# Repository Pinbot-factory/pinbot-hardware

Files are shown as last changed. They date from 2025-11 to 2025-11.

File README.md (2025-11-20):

**Pinbot** is an open-source platform for quickly building test jigs for electronics QA. The platform is made up of mechanical fixtures, control electronics, jig-level software and backend to store all test results.

**This repo is in active development. New HW will be released soon.**

## Pinbot Hardware
This repo is dedicated for electronics of a typical Pinbot jig. Now it is a compact carrier board for Raspberry Pi 0.

**It features:**
- 8 channels ADC 0-24V
- 8 channels GPIO 0-24V
- 4 signal relays
- USB hub (4x, with power control)
- Qwiic connector for I2C
- USB-C for power supply

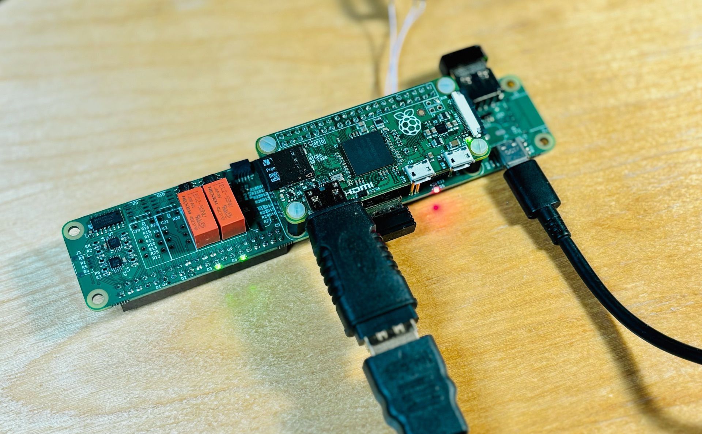
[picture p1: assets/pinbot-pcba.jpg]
Pinbot PCBA


Carrier board is 150x30mm. Repo includes KiCAD source files, generated gerbers, BOM, and everything to produce it on your own.

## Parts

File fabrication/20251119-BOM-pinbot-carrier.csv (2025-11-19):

Reference | Value | Footprint | Qty | DNP | LCSC Part # | Mouser Part #
A1 | Raspberry Pi Zero v1.3 | Raspberry_Pi_Zero_v.1.3_Hat:RASPI_ZERO_FULL | 1
C1,C4,C5,C6,C7,C9,C10,C17,C18,C19,C20,C21,C22,C23 | 0.1uFx50V | Capacitor_SMD:C_0603_1608Metric | 14 |  | C282519 | CGA3E2X7R1H104M080AA
C2 | 0.01uFx50V | Capacitor_SMD:C_0603_1608Metric | 1 |  | C100042 | 06031C103K4T4A
C3,C8,C12,C13,C14 | 100uFx16V | Capacitor_SMD:CP_Elec_6.3x5.4 | 5 |  | C129250 | UWT1C101MCL1GB
C11,C15,C16 | 10uFx10V | Capacitor_SMD:C_0603_1608Metric | 3 |  | C2959727 | GRM188Z71A106MA73J
D1,D2,D3,D4,D6,D7,D8,D9 | LTST-S270KGKT | LED_0603_1608Metric_side:LED_0603_1608Metric_side | 8 |  | C125113 | LTST-S270KGKT
D5 | LTST-S270KRKT | LED_0603_1608Metric_side:LED_0603_1608Metric_side | 1 |  | C125114 | LTST-S270KRKT
D10,D11,D12,D13,D14,D15,D16,D17 | ESD5Z3.3T5G | Diode_SMD:D_SOD-523 | 8 |  | C22440077 | ESD5Z3.3T5G
F1 | MF-NSMF200-2 | Fuse:Fuse_1206_3216Metric | 1 |  | C89656 | MF-NSMF200-2
H1,H2,H3,H4 | MountingHole | MountingHoles:MountingHole_3.2mm_M3_keepouts | 4 | DNP
J1 | USB4105-GF-A-120 | Connector_USB:USB_C_Receptacle_GCT_USB4105-xx-A_16P_TopMnt_Horizontal | 1 |  | C709358 | USB4105-GF-A-120
J2 | Conn_02x20_Odd_Even | Connector_PinSocket_2.54mm:PinSocket_2x20_P2.54mm_Vertical | 1 |  | C2977589
J3 | HC-1.0-4PWT | Connector_JST:JST_SH_SM04B-SRSS-TB_1x04-1MP_P1.00mm_Horizontal | 1 |  | C2845363 | 10147606-00004LF
J4 | SM06B-SRSS-TB | SM06B-SRSS-TB:JST_SM06B-SRSS-TB | 1 |  | C160405 | 10147606-00006LF
J5,J6,J7 | USB_A | USB1125-GF-B:GCT_USB1125-GF-B_REVA | 3 |  | C5984324 | USB1125-GF-B
JP1,JP2 | SolderJumper_2_Open | Jumper:SolderJumper-2_P1.3mm_Open_RoundedPad1.0x1.5mm | 2 | DNP
K1,K2,K3,K4 | EC2-5SNU | Relay_THT:Relay_DPDT_Kemet_EC2 | 4 |  | C2153173 | EC2-5SNU
R1,R2,R3,R4,R12,R13,R14,R15 | 820k | Resistor_SMD:R_0603_1608Metric | 8 |  | C2907070 | ERJ-3EKF8203V
R5,R6,R8,R9,R16,R17,R20,R25 | 120k | Resistor_SMD:R_0603_1608Metric | 8 |  | C2930027 | CRGCQ0603F120K
R7 | 1M | Resistor_SMD:R_0603_1608Metric | 1 |  | C107698 | ASC0603-1M0FT5
R10,R11 | 5.1k | Resistor_SMD:R_0603_1608Metric | 2 |  | C2907114 | ERJ-3EKF5101V
R18,R19,R21,R22,R23,R24,R26,R27,R35,R36,R37,R42,R43 | 10k | Resistor_SMD:R_0603_1608Metric | 13 |  | C2907113 | RMC1/16K1002DTP
R28 | 100R | Resistor_SMD:R_0603_1608Metric | 1 |  | C2907089 | CRT0603-DY-1000ELF
R29,R30,R31,R32,R33,R34,R39,R40,R41 | 330R | Resistor_SMD:R_0603_1608Metric | 9 |  | C23138 | RMCF0603FT330R
R38 | 2.7k | Resistor_SMD:R_0603_1608Metric | 1 |  | C13167 | AC0603FR-102K7L
U1 | TCA9535PWR | Package_SO:TSSOP-24_4.4x7.8mm_P0.65mm | 1 |  | C22396388 | TCA9535PWR
U2,U7 | ADS1015IDGS | Package_SO:TSSOP-10_3x3mm_P0.5mm | 2 |  | C193969 | ADS1015IDGS
U8 | 74HC04 | Package_SO:SOIC-14_3.9x8.7mm_P1.27mm | 1 |  | C5590 | 74HC04D,653
U9,U10,U11,U12 | ZXBM5210-S | Package_SO:SOIC-8_3.9x4.9mm_P1.27mm | 4 |  | C20627211 | ZXBM5210-S
U13,U19 | MIC2026-2xM | Package_SO:SOIC-8_3.9x4.9mm_P1.27mm | 2 |  | C148072 | MIC2026-2YM
U14,U15,U16,U17 | USBLC6-2SC6 | Package_TO_SOT_SMD:SOT-23-6 | 4 |  | C5180249 | USBLC6-2SC6
U18 | FE1.1s | Package_SO:SSOP-28_3.9x9.9mm_P0.635mm | 1 |  | C9359
Y1 | 12MHz | Crystal:Crystal_SMD_3225-4Pin_3.2x2.5mm | 1 |  | C70565 | ECS-120-12-33-AEN-TR

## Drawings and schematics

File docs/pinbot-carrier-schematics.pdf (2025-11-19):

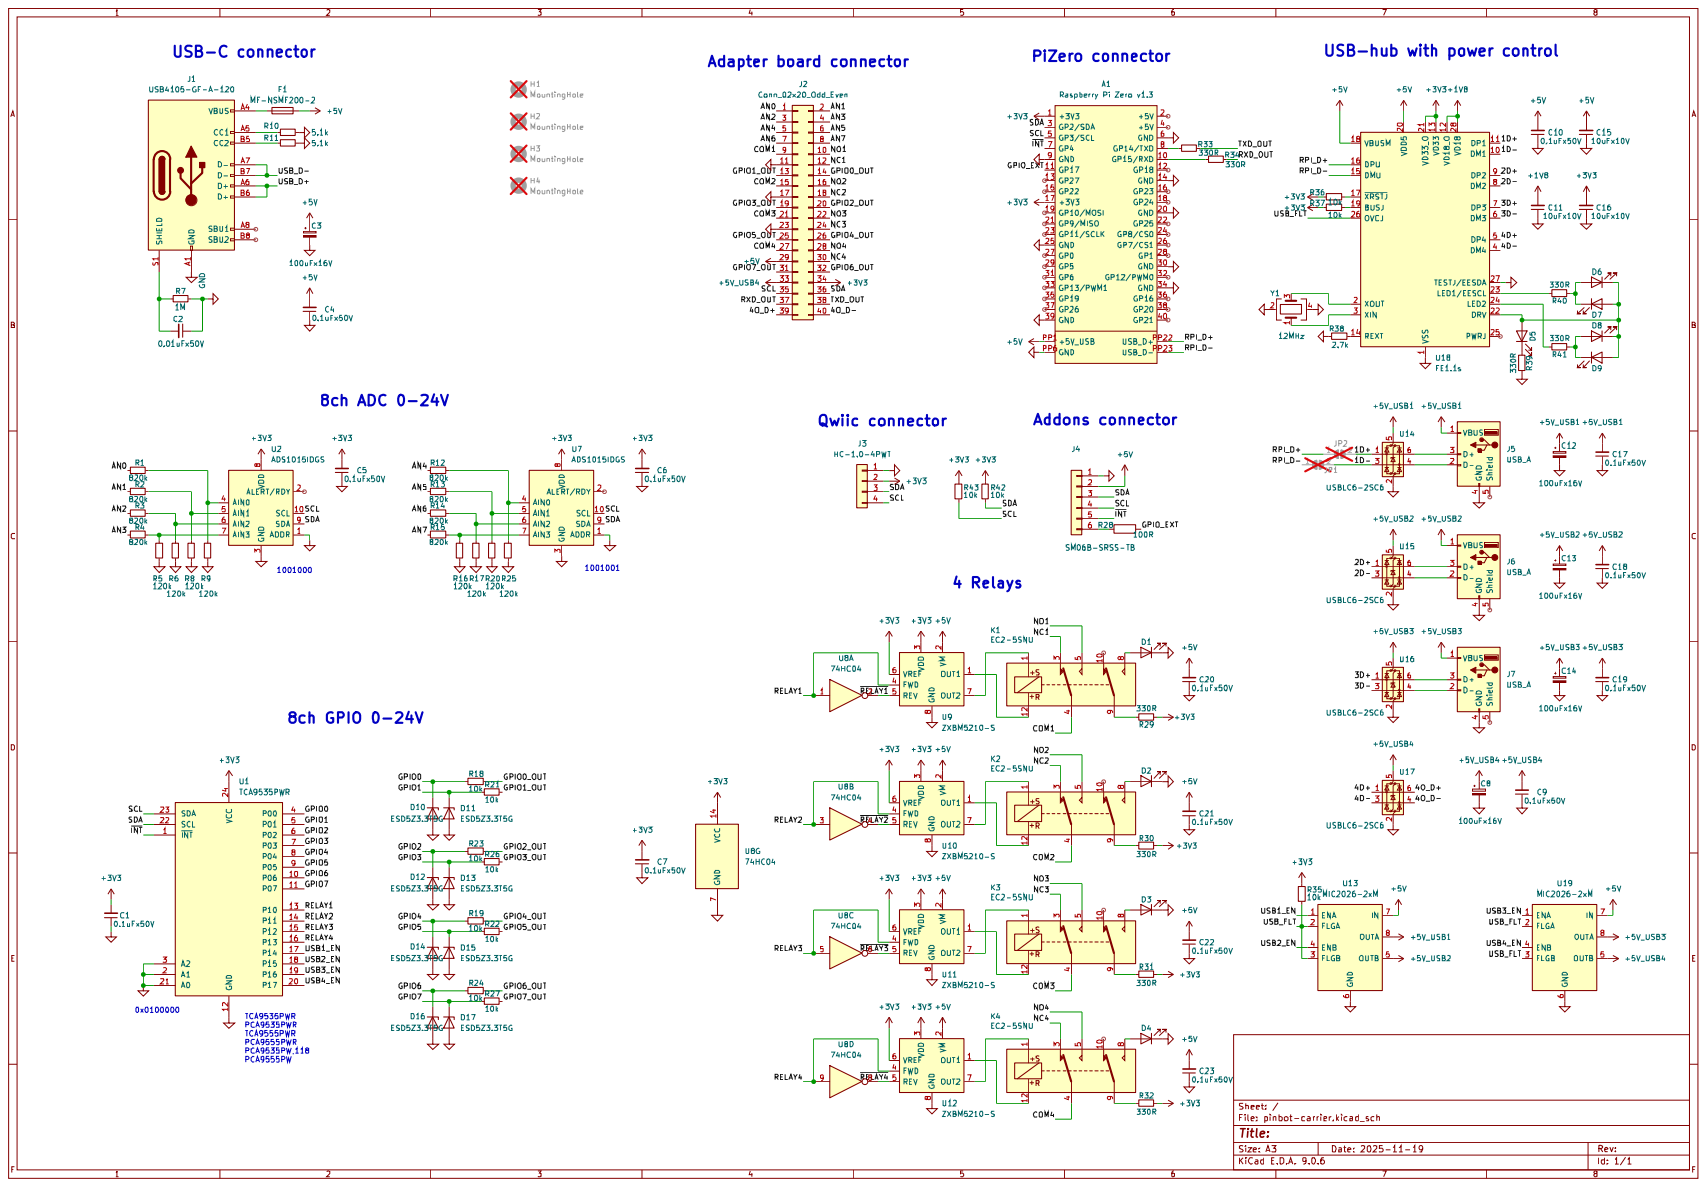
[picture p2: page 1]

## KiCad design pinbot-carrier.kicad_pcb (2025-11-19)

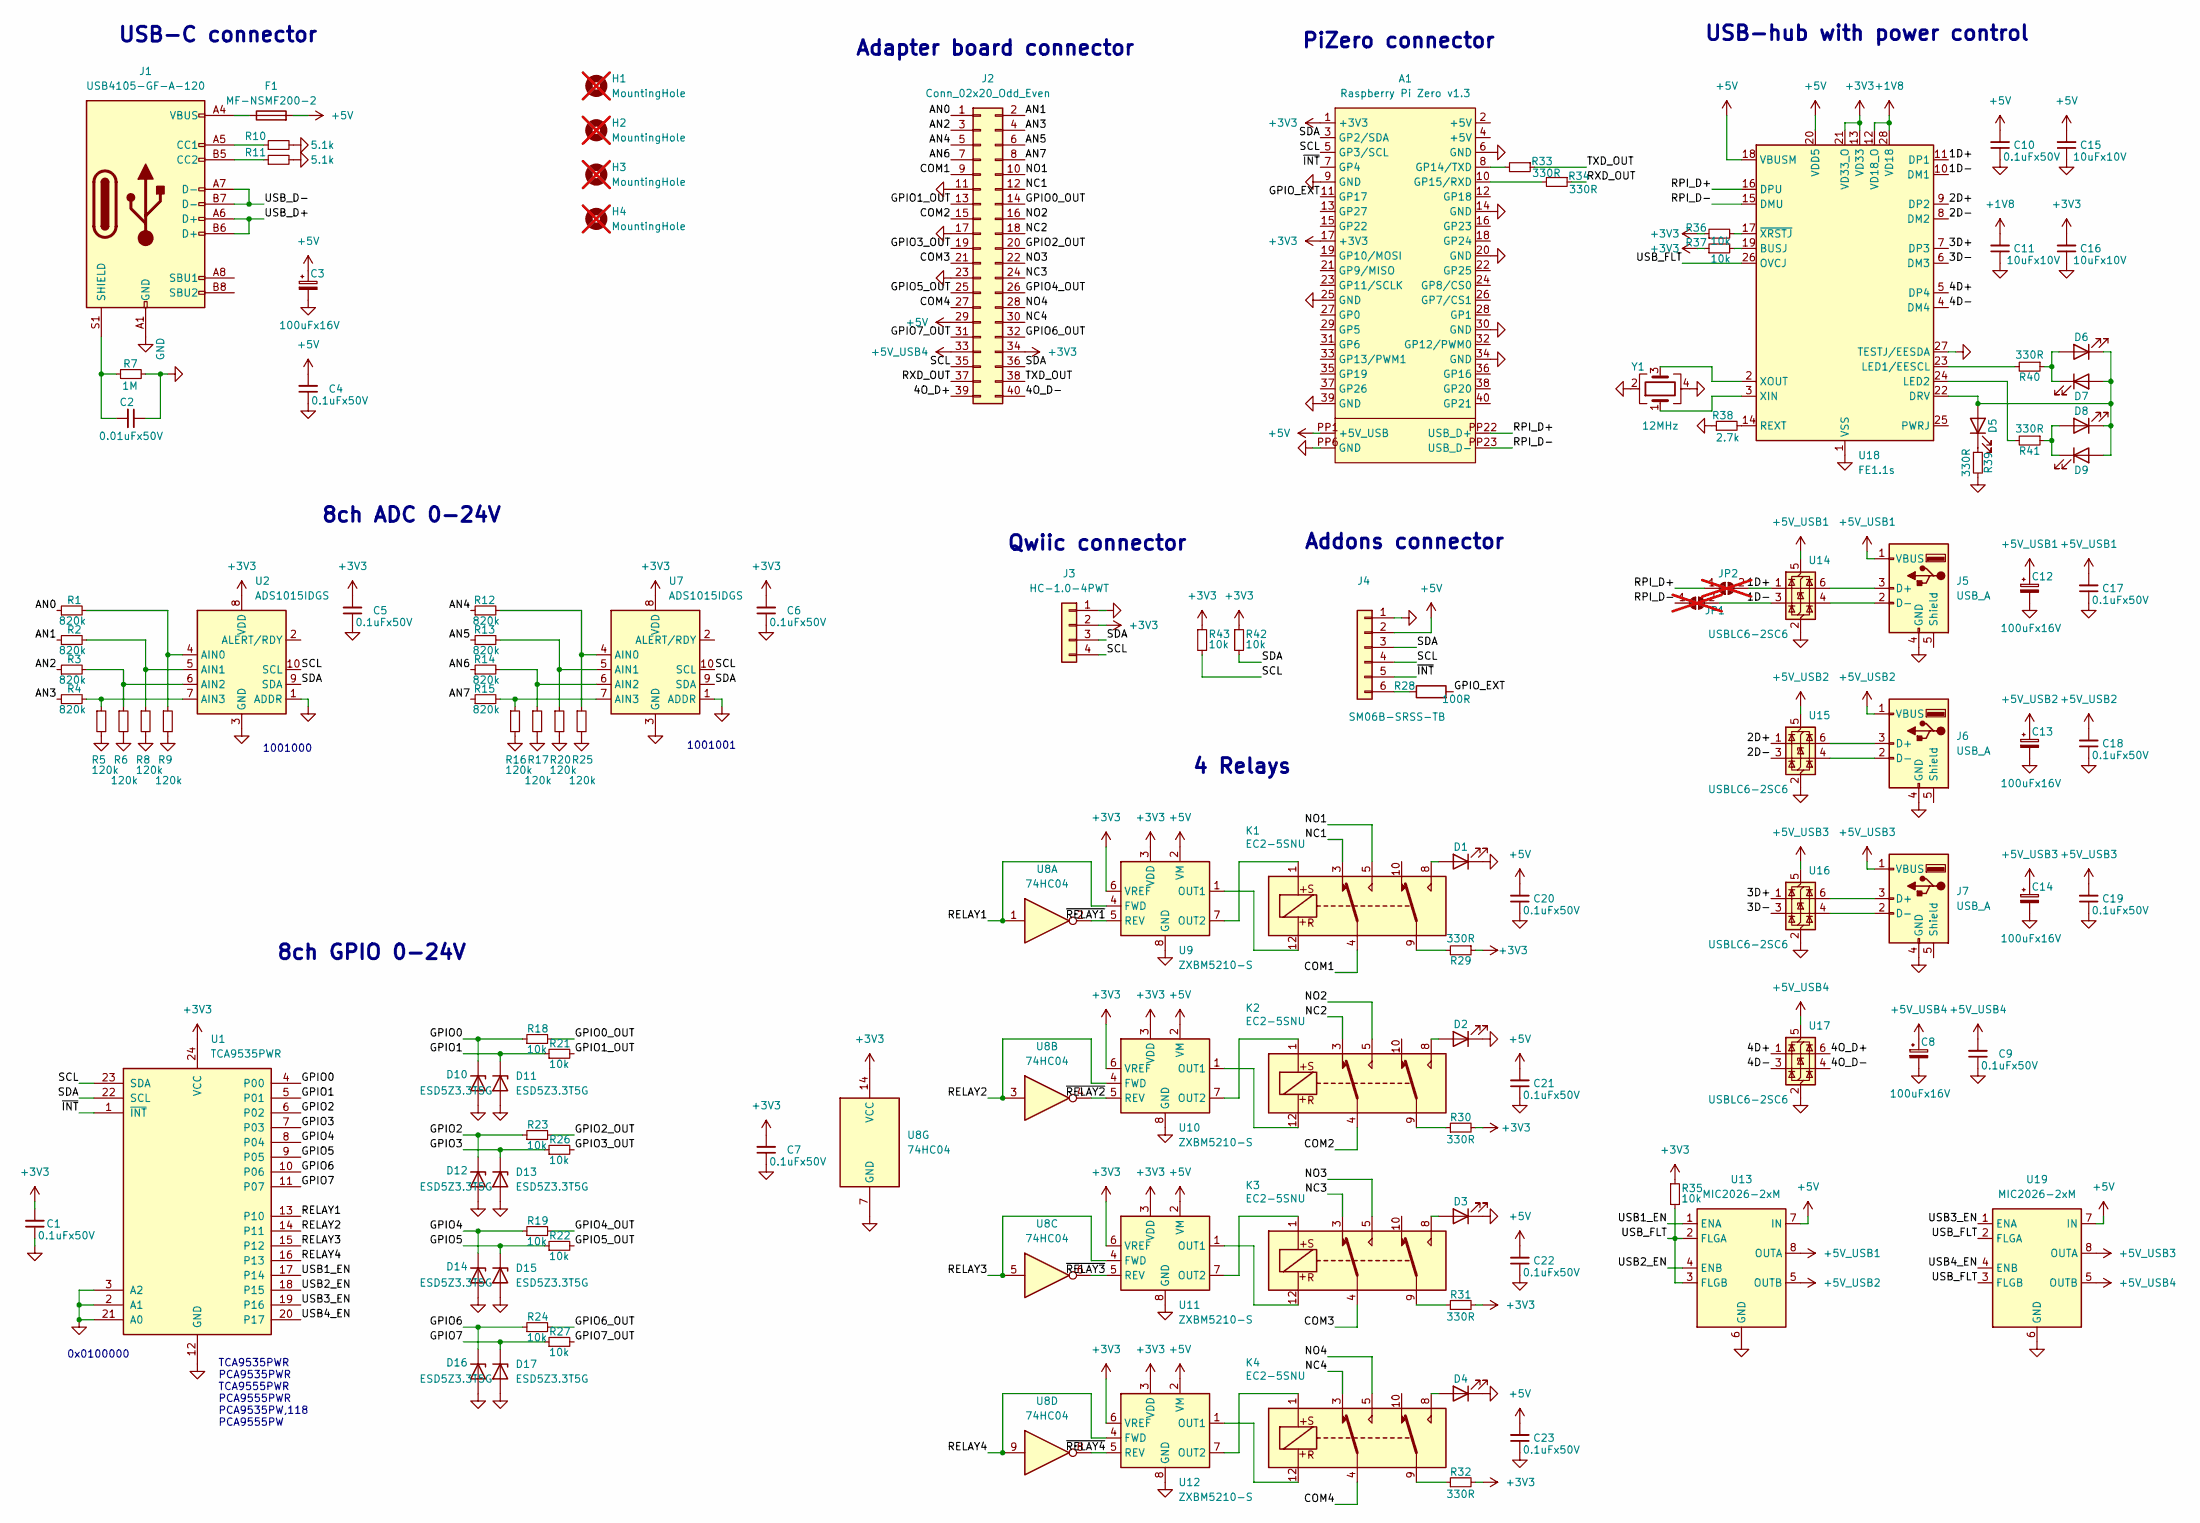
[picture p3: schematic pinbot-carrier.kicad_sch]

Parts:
A1: Raspberry Pi Zero v1.3; RASPI_ZERO_FULL
C1: 0.1uFx50V; C_0603_1608Metric; Mouser Part # CGA3E2X7R1H104M080AA
C2: 0.01uFx50V; C_0603_1608Metric; Mouser Part # 06031C103K4T4A; LCSC Part # C100042
C3, C8, C12, C13, C14: 100uFx16V; CP_Elec_6.3x5.4; Mouser Part # UWT1C101MCL1GB; LCSC Part # C129250
C4, C5, C6, C7, C9, C10, C17, C18, C19, C20, C21, C22, C23: 0.1uFx50V; C_0603_1608Metric; Mouser Part # CGA3E2X7R1H104M080AA; LCSC Part # C282519
C11, C15, C16: 10uFx10V; C_0603_1608Metric; Mouser Part # GRM188Z71A106MA73J; LCSC Part # C2959727
D1, D2, D3, D4, D6, D7, D8, D9: LTST-S270KGKT; LED_0603_1608Metric_side; Mouser Part # LTST-S270KGKT; LCSC Part # C125113
D5: LTST-S270KRKT; LED_0603_1608Metric_side; Mouser Part # LTST-S270KRKT; LCSC Part # C125114
D10, D11, D12, D13, D14, D15, D16, D17: ESD5Z3.3T5G; D_SOD-523; Mouser Part # ESD5Z3.3T5G
F1: MF-NSMF200-2; Fuse_1206_3216Metric; Mouser Part # MF-NSMF200-2; LCSC Part # C89656
H1, H2, H3, H4: MountingHole; MountingHole_3.2mm_M3_keepouts; not fitted
J1: USB4105-GF-A-120; USB_C_Receptacle_GCT_USB4105-xx-A_16P_TopMnt_Horizontal; Mouser Part # USB4105-GF-A-120
J2: Conn_02x20_Odd_Even; PinSocket_2x20_P2.54mm_Vertical; LCSC Part # C2977589
J3: HC-1.0-4PWT; JST_SH_SM04B-SRSS-TB_1x04-1MP_P1.00mm_Horizontal; Mouser Part # 10147606-00004LF; LCSC Part # C2845363
J4: SM06B-SRSS-TB; JST_SM06B-SRSS-TB; Mouser Part # 10147606-00006LF; LCSC Part # C160405
J5, J6, J7: USB_A; GCT_USB1125-GF-B_REVA; Mouser Part # USB1125-GF-B
JP1, JP2: SolderJumper_2_Open; SolderJumper-2_P1.3mm_Open_RoundedPad1.0x1.5mm; not fitted
K1, K2, K3, K4: EC2-5SNU; Relay_DPDT_Kemet_EC2; Mouser Part # EC2-5SNU
R1, R2, R3, R4, R12, R13, R14, R15: 820k; R_0603_1608Metric; Mouser Part # ERJ-3EKF8203V; LCSC Part # C2907070
R5, R6, R8, R9, R16, R17, R20, R25: 120k; R_0603_1608Metric; Mouser Part # CRGCQ0603F120K; LCSC Part # C2930027
R7: 1M; R_0603_1608Metric; Mouser Part # ASC0603-1M0FT5; LCSC Part # C107698
R10, R11: 5.1k; R_0603_1608Metric; Mouser Part # ERJ-3EKF5101V; LCSC Part # C2907114
R18, R19, R21, R22, R23, R24, R26, R27, R35, R36, R37, R42, R43: 10k; R_0603_1608Metric; Mouser Part # RMC1/16K1002DTP; LCSC Part # C2907113
R28: 100R; R_0603_1608Metric; Mouser Part # CRT0603-DY-1000ELF; LCSC Part # C2907089
R29, R30, R31, R32, R33, R34, R39, R40, R41: 330R; R_0603_1608Metric; Mouser Part # RMCF0603FT330R; LCSC Part # C23138
R38: 2.7k; R_0603_1608Metric; Mouser Part # AC0603FR-102K7L; LCSC Part # C13167
U1: TCA9535PWR; TSSOP-24_4.4x7.8mm_P0.65mm; Mouser Part # TCA9535PWR
U2, U7: ADS1015IDGS; TSSOP-10_3x3mm_P0.5mm; Mouser Part # ADS1015IDGS
U8: 74HC04; SOIC-14_3.9x8.7mm_P1.27mm; Mouser Part # 74HC04D,653
U9, U10, U11, U12: ZXBM5210-S; SOIC-8_3.9x4.9mm_P1.27mm; Mouser Part # ZXBM5210-S
U13, U19: MIC2026-2xM; SOIC-8_3.9x4.9mm_P1.27mm; Mouser Part # MIC2026-2YM
U14, U15, U16, U17: USBLC6-2SC6; SOT-23-6; Mouser Part # USBLC6-2SC6
U18: FE1.1s; SSOP-28_3.9x9.9mm_P0.635mm; LCSC Part # C9359
Y1: 12MHz; Crystal_SMD_3225-4Pin_3.2x2.5mm; PartNumber X322512MOB4SI; LCSC Part # C70565

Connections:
+1V8: C11.2, U18.12 (VD18_O), U18.28 (VD18)
+3V3: A1.1 (+3V3), A1.17 (+3V3), C1.2, C5.2, C6.2, C7.2, C16.2, J2.34, J3.2, R29.1, R30.2, R31.2, R32.2, R35.1, R36.1, R37.1, R42.1, R43.1, U1.24 (VCC), U2.8 (VDD), U7.8 (VDD), U8.14 (VCC), U9.3 (VDD), U9.6 (VREF), U10.3 (VDD), U10.6 (VREF), U11.3 (VDD), U11.6 (VREF), U12.3 (VDD), U12.6 (VREF), U18.13 (VD33), U18.21 (VD33_O)
+5V: A1.PP1 (+5V_USB), C3.1, C4.2, C10.2, C15.2, C20.2, C21.2, C22.2, C23.2, F1.2, J2.29, J4.2, U9.2 (VM), U10.2 (VM), U11.2 (VM), U12.2 (VM), U13.7 (IN), U18.18 (VBUSM), U18.20 (VDD5), U19.7 (IN)
+5V_USB1: C12.1, C17.2, J5.1 (VBUS), U13.8 (OUTA), U14.5 (VBUS)
+5V_USB2: C13.1, C18.2, J6.1 (VBUS), U13.5 (OUTB), U15.5 (VBUS)
+5V_USB3: C14.1, C19.2, J7.1 (VBUS), U16.5 (VBUS), U19.8 (OUTA)
+5V_USB4: C8.1, C9.2, J2.33, U17.5 (VBUS), U19.5 (OUTB)
/1D+: JP2.2 (B), U14.1 (I/O1), U18.11 (DP1)
/1D-: JP1.2 (B), U14.3 (I/O2), U18.10 (DM1)
/2D+: U15.1 (I/O1), U18.9 (DP2)
/2D-: U15.3 (I/O2), U18.8 (DM2)
/3D+: U16.1 (I/O1), U18.7 (DP3)
/3D-: U16.3 (I/O2), U18.6 (DM3)
/4D+: U17.1 (I/O1), U18.5 (DP4)
/4D-: U17.3 (I/O2), U18.4 (DM4)
/4O_D+: J2.39, U17.6 (I/O1)
/4O_D-: J2.40, U17.4 (I/O2)
/AN0: J2.1, R1.1
/AN1: J2.2, R2.1
/AN2: J2.3, R3.1
/AN3: J2.4, R4.1
/AN4: J2.5, R12.1
/AN5: J2.6, R13.1
/AN6: J2.7, R14.1
/AN7: J2.8, R15.1
/COM1: J2.9, K1.4
/COM2: J2.15, K2.4
/COM3: J2.21, K3.4
/COM4: J2.27, K4.4
/GPIO0: D10.1 (K), R18.1, U1.4 (P00)
/GPIO0_OUT: J2.14, R18.2
/GPIO1: D11.1 (K), R21.1, U1.5 (P01)
/GPIO1_OUT: J2.13, R21.2
/GPIO2: D12.1 (K), R23.1, U1.6 (P02)
/GPIO2_OUT: J2.20, R23.2
/GPIO3: D13.1 (K), R26.1, U1.7 (P03)
/GPIO3_OUT: J2.19, R26.2
/GPIO4: D14.1 (K), R19.1, U1.8 (P04)
/GPIO4_OUT: J2.26, R19.2
/GPIO5: D15.1 (K), R22.1, U1.9 (P05)
/GPIO5_OUT: J2.25, R22.2
/GPIO6: D16.1 (K), R24.1, U1.10 (P06)
/GPIO6_OUT: J2.32, R24.2
/GPIO7: D17.1 (K), R27.1, U1.11 (P07)
/GPIO7_OUT: J2.31, R27.2
/GPIO_EXT: A1.11 (GP17), R28.2
/NC1: J2.12, K1.3
/NC2: J2.18, K2.3
/NC3: J2.24, K3.3
/NC4: J2.30, K4.3
/NO1: J2.10, K1.5
/NO2: J2.16, K2.5
/NO3: J2.22, K3.5
/NO4: J2.28, K4.5
/RELAY1: U1.13 (P10), U8.1, U9.4 (FWD)
/RELAY2: U1.14 (P11), U8.3, U10.4 (FWD)
/RELAY3: U1.15 (P12), U8.5, U11.4 (FWD)
/RELAY4: U1.16 (P13), U8.9, U12.4 (FWD)
/RPI_D+: A1.PP22 (USB_D+), JP2.1 (A), U18.16 (DPU)
/RPI_D-: A1.PP23 (USB_D-), JP1.1 (A), U18.15 (DMU)
/RXD_OUT: J2.37, R34.1
/SCL: A1.5 (GP3/SCL), J2.35, J3.4, J4.4, R43.2, U1.23 (SDA), U2.10 (SCL), U7.10 (SCL)
/SDA: A1.3 (GP2/SDA), J2.36, J3.3, J4.3, R42.2, U1.22 (SCL), U2.9 (SDA), U7.9 (SDA)
/TXD_OUT: J2.38, R33.1
/USB1_EN: U1.17 (P14), U13.1 (ENA)
/USB2_EN: U1.18 (P15), U13.4 (ENB)
/USB3_EN: U1.19 (P16), U19.1 (ENA)
/USB4_EN: U1.20 (P17), U19.4 (ENB)
/USB_D+: J1.A6 (D+), J1.B6 (D+)
/USB_D-: J1.A7 (D-), J1.B7 (D-)
/USB_FLT: R35.2, U13.2 (FLGA), U13.3 (FLGB), U18.26 (OVCJ), U19.2 (FLGA), U19.3 (FLGB)
/~INT: A1.7 (GP4), J4.5, U1.1 (~INT)
/~RELAY1: U8.2, U9.5 (REV)
/~RELAY2: U8.4, U10.5 (REV)
/~RELAY3: U8.6, U11.5 (REV)
/~RELAY4: U8.8, U12.5 (REV)
GND: A1.6 (GND), A1.9 (GND), A1.14 (GND), A1.20 (GND), A1.25 (GND), A1.30 (GND), A1.34 (GND), A1.39 (GND), A1.PP6 (GND), C1.1, C2.1, C3.2, C4.1, C5.1, C6.1, C7.1, C8.2, C9.1, C10.1, C11.1, C12.2, C13.2, C14.2, C15.1, C16.1, C17.1, C18.1, C19.1, C20.1, C21.1, C22.1, C23.1, D1.1 (K), D2.1 (K), D3.1 (K), D4.1 (K), D10.2 (A), D11.2 (A), D12.2 (A), D13.2 (A), D14.2 (A), D15.2 (A), D16.2 (A), D17.2 (A), J1.A1 (GND), J1.A12 (GND), J1.B1 (GND), J1.B12 (GND), J2.11, J2.17, J2.23, J3.1, J4.1, J5.4 (GND), J6.4 (GND), J7.4 (GND), R5.2, R6.2, R7.2, R8.2, R9.2, R10.2, R11.2, R16.2, R17.2, R20.2, R25.2, R38.1, R39.2, U1.2 (A1), U1.3 (A2), U1.12 (GND), U1.21 (A0), U2.1 (ADDR), U2.3 (GND), U7.1 (ADDR), U7.3 (GND), U8.7 (GND), U9.8 (GND), U10.8 (GND), U11.8 (GND), U12.8 (GND), U13.6 (GND), U14.2 (GND), U15.2 (GND), U16.2 (GND), U17.2 (GND), U18.1 (VSS), U18.27 (TESTJ/EESDA), U19.6 (GND), Y1.2, Y1.4
unnamed: A1.8 (GP14/TXD), R33.2
unnamed: A1.10 (GP15/RXD), R34.2
unnamed: D1.2 (A), K1.8
unnamed: D2.2 (A), K2.8
unnamed: D3.2 (A), K3.8
unnamed: D4.2 (A), K4.8
unnamed: D5.2 (A), D6.1 (K), D7.2 (A), D8.1 (K), D9.2 (A), U18.22 (DRV)
unnamed: D5.1 (K), R39.1
unnamed: D6.2 (A), D7.1 (K), R40.1
unnamed: D8.2 (A), D9.1 (K), R41.1
unnamed: F1.1, J1.A4 (VBUS), J1.A9 (VBUS), J1.B4 (VBUS), J1.B9 (VBUS)
unnamed: J1.A5 (CC1), R10.1
unnamed: J1.B5 (CC2), R11.1
unnamed: C2.2, J1.S1 (SHIELD), R7.1
unnamed: J4.6, R28.1
unnamed: J5.3 (D+), U14.6 (I/O1)
unnamed: J5.2 (D-), U14.4 (I/O2)
unnamed: J6.3 (D+), U15.6 (I/O1)
unnamed: J6.2 (D-), U15.4 (I/O2)
unnamed: J7.3 (D+), U16.6 (I/O1)
unnamed: J7.2 (D-), U16.4 (I/O2)
unnamed: K1.9, R29.2
unnamed: K2.9, R30.1
unnamed: K3.9, R31.1
unnamed: K4.9, R32.1
unnamed: R1.2, R9.1, U2.4 (AIN0)
unnamed: R2.2, R8.1, U2.5 (AIN1)
unnamed: R3.2, R6.1, U2.6 (AIN2)
unnamed: R4.2, R5.1, U2.7 (AIN3)
unnamed: R12.2, R25.1, U7.4 (AIN0)
unnamed: R13.2, R20.1, U7.5 (AIN1)
unnamed: R14.2, R17.1, U7.6 (AIN2)
unnamed: R15.2, R16.1, U7.7 (AIN3)
unnamed: K1.12, U9.1 (OUT1)
unnamed: K1.1, U9.7 (OUT2)
unnamed: K2.12, U10.1 (OUT1)
unnamed: K2.1, U10.7 (OUT2)
unnamed: K3.12, U11.1 (OUT1)
unnamed: K3.1, U11.7 (OUT2)
unnamed: K4.12, U12.1 (OUT1)
unnamed: K4.1, U12.7 (OUT2)
unnamed: R37.2, U18.19 (BUSJ)
unnamed: R40.2, U18.23 (LED1/EESCL)
unnamed: R41.2, U18.24 (LED2)
unnamed: R38.2, U18.14 (REXT)
unnamed: U18.3 (XIN), Y1.1
unnamed: U18.2 (XOUT), Y1.3
unnamed: R36.2, U18.17 (~XRSTJ)

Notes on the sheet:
PiZero connector
USB-C connector
0x0100000
4 Relays
8ch ADC 0-24V
Qwiic connector
1001000
1001001
TCA9535PWR PCA9535PWR TCA9555PWR PCA9555PWR PCA9535PW,118 PCA9555PW
USB-hub with power control
Addons connector
8ch GPIO 0-24V
Adapter board connector

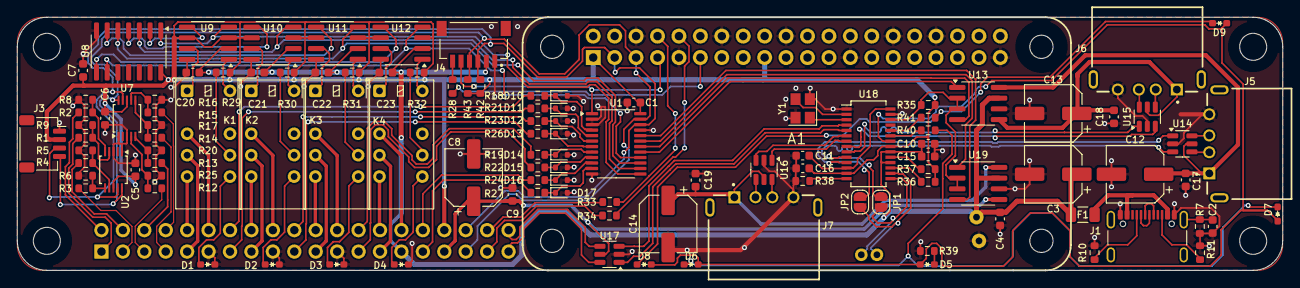
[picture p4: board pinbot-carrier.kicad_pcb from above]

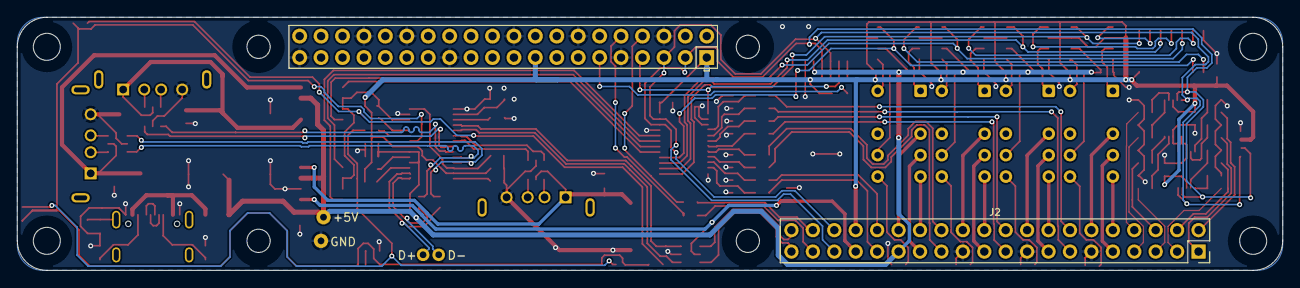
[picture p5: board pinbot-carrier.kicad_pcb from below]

Board: 2 copper layers, 150.0 x 30.0 mm, 118 parts (2 on the bottom side), 125 nets.

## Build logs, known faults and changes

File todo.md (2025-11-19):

# TODO

## FE1.1s
- unconnect pin 27 (TEST)
- unconnect pins 12 and 13
- unconnect pin 28
- put 3.3 thru devider 5.1k/10k to VBUSM pin 18
- no need for 1.8v 10u cap
- 12pF caps near quarz crystal
- OVCJ pull-up put near chip on schematic to make the block transferrable

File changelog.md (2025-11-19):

# Changelog

## 20251119
- Project renamed
- Directory structure cleanup
- Manufacturing files updated
